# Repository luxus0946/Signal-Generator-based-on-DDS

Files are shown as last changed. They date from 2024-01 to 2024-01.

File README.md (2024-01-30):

# 基于DDS的信号发生器
 ---
### 基本概述

本设计使用STC8H8K64U单片机通过IO端口控制波形发生器AD9833输出波形，经过低通滤波单元接入由MCP41010数字电位器控制的MS8051运放来将产生的信号幅值放大，并且配置了相应的按键输入和液晶屏显示波形的幅值、相位、频率等数据。

### 硬件设计

本设计中基于DDS的多功能信号发生器使用STC8H8K64U实验板通过IO端口控制波形发生器AD9833模块输出波形，经过一个低通滤波单元接入由MCP41010数字电位器控制的MS8051运放进行幅值放大，具体产生的波形、幅值、相位、频率等数据通过液晶屏显示出来，理想测定值通过按键进行人机交互，其中显示单元由12864的液晶模块组成，单片机通过IIC协议控制液晶屏的显示，整个系统通过USB提供电源，外加的接口进行信号的下载和输入。
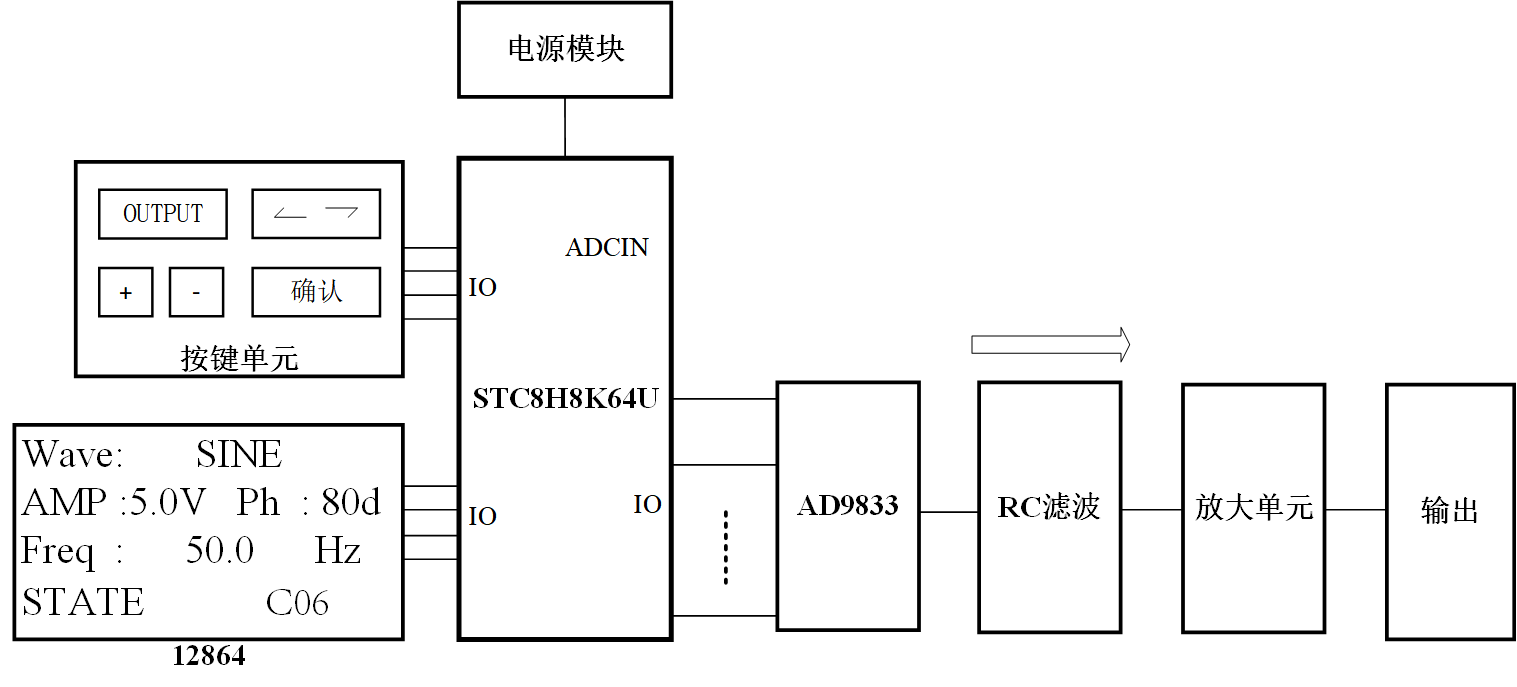
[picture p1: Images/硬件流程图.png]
硬件设计


##### 控制单元
STC8H8K64U具有16个口线，其中P1.4、P1.5、P1.6、P1.7四个口线连接AD9833进行控制主要波形的输出，P1.0、P1.1两个口线连接OLED液晶屏显示波形、幅值、相位、频率等数据信息，P3.4、P3.5、P3.6、P3.7四个口线连接四个按键，进行模式、选择、加和减的控制，P3.3一个口线连接开关进行设置的自锁功能控制，控制单元的电路原理图如下所示。

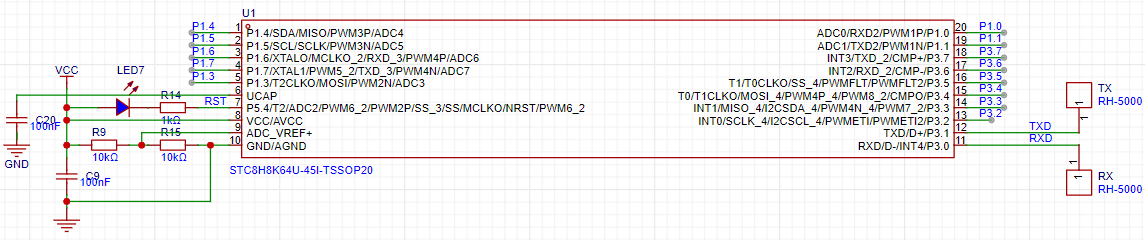
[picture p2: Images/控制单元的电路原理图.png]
控制单元

##### 信号发生模块

DDS的实现方式有两种，即通过程序实现和通过DDS芯片实现，通过程序实现需要DAC模块，通过DDS芯片实现需要AD9833模块，本组课程设计采用通过DDS芯片实现的方式。
在与STC8H8K64U实验板的连接传输过程中，SDATA引脚进行串行数据的输入，SCLK引脚进行串行时钟的输入，FSYNC引脚进行低有效控制的输入，最后通过VOUT引脚输出方波、正弦波、三角波等信号，AD9833信号发生模块的电路原理图如下所示。

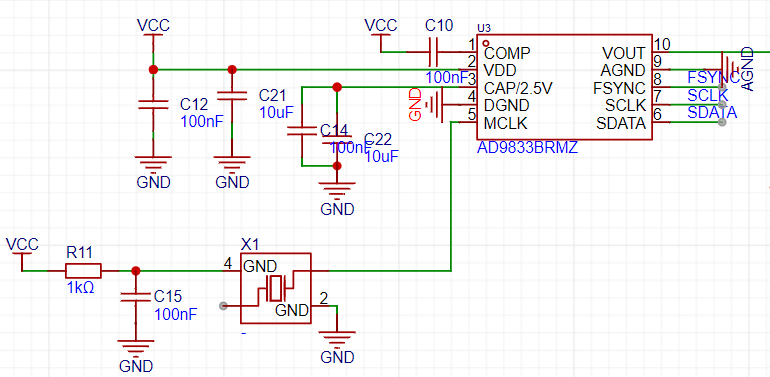
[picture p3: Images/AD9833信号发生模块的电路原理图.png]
信号发生模块


##### 滤波放大模块

考虑到输出的波形可能不是理想的，所以对于AD9833输出的信号采用低通滤波单元进行滤波处理，降低高频噪声对整个系统电路的影响。

由于选用的信号发生器其中自带数字电位器进行阻值调节，所以初步方案的放大单元由MCP41010数字电位器和AD8051运算放大器构成，但在实际测试过程中，AD8051运放的增益带宽积过小，经查阅资料后把AD8051运放改成增益带宽积较大的MS8051运算放大器。

MCP41010数字电位器的CS引脚为数字电位器的片选端，只有为低电平时，命令字和数据字才能进入16位移位寄存器，滤波放大模块的电路原理图如图所示。

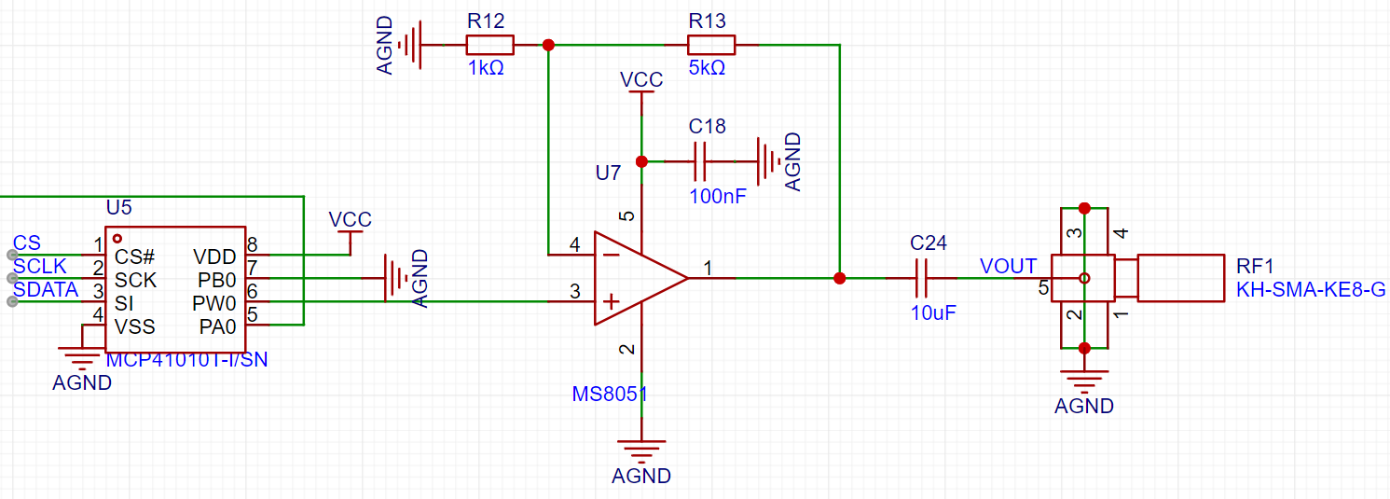
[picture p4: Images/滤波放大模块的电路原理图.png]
滤波放大模块


### 软件设计
本设计中使用Keil5编写C语言程序控制STC8H8K64U通过SPI协议与AD9833芯片进行通信输出波形，复用AD9833占用的SPI口线对MCP41010数字电位器进行控制来调整幅值。具体产生的波形、幅值、相位、频率等数据通过液晶屏显示出来，理想测定值通过按键进行人机交互，其中显示单元由12864的液晶模块组成，单片机通过IIC协议控制液晶屏的显示。程序流程图如下

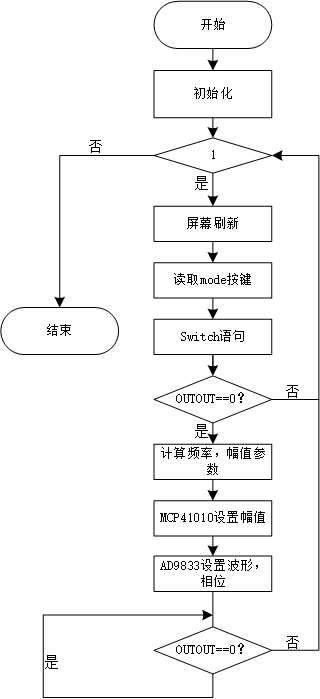
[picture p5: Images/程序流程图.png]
软件设计


#### 相关硬件驱动

##### OLED驱动

我们先对每一个部分进行代码实现，然后调用所实现的函数进行组合发送一个字节的数据。然后根据汉昇的数据手册分别发送命令（command）与数据（data）。我们可以通过发送命令对屏幕进行设置模式，清屏等操作。根据上述流程我们实现我们所需要使用的驱动函数，详细代码细节可见附录，IIC协议的控制流程图如图所示。

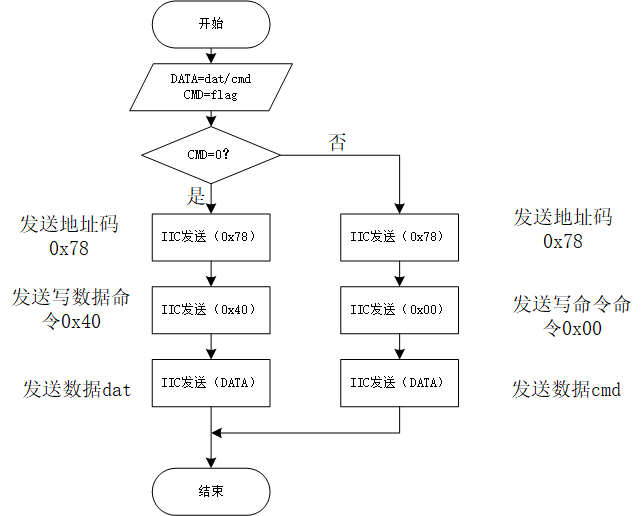
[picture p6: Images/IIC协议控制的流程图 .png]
OLED驱动


##### AD9833驱动 

AD9833是可编程波形发生器,能够产生正弦波、三角波、方波输出。通过软件编程进行控制相位和频率，频率寄存器是28位的。

AD9833有3根串行接口线FSYNC、SCLK、SDATA，在串口时钟SCLK的作用下，数据是以16位的方式加载到设备上，FSYNC引脚是使能引脚，低电平有效。进行串行数据传输时，FSYNC引脚必须置低,要注意FSYNC有效到SCLK下降沿的建立时间t7的最小值。FSYNC置低后，在16个SCLK的下降沿数据被送到AD9833的输入移位寄存器，在第16个SCLK的下降沿FSYNC可以被置高。

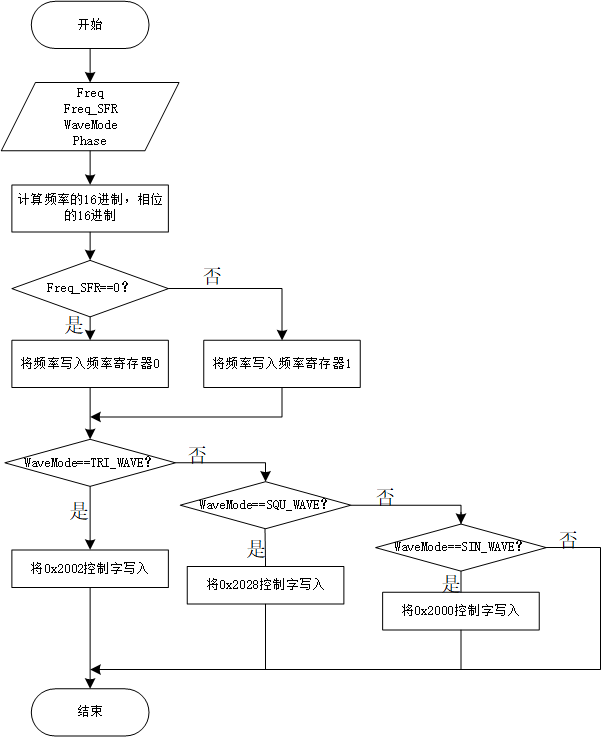
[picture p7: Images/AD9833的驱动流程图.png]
AD9833驱动


##### MCP41010驱动
本方案使用MCP41010数字电位器与MS8051运算放大器组成信号放大单元。MCP41010使用电位器工作模式，MS8051与电阻搭建11倍固定增益放大电路。MCP41010有256个抽头，可以对电压有较为精细的控制。由于我们选用的为MCP41010只有#CS，SCK，SI三条信号线，在写入控制字时需要将CS拉低由于MCP41010的SCK和SI与AD9833的SCLK、SDATA是复用的，所以在写入AD9833控制字时需要吧CS拉高，对MCP41010操作时把CS拉低。否则回发生冲突，无法实现复用，MCP41010控制时序图如图4.7所示，MCP41010的驱动流程图如图所示。

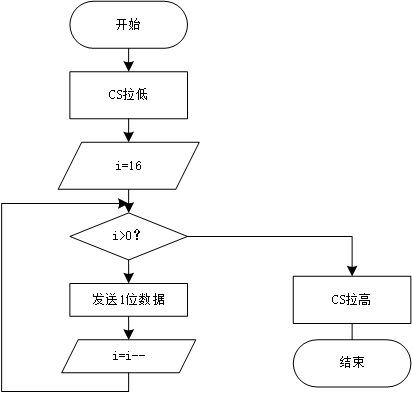
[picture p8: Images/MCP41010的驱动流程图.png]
MCP41010驱动


##### EEPROM驱动
为了更好的用户体验，我们设计了掉电保存上一次输出的参数的功能。我们使用STC8H单片机内部的EEPROM来实现这个功能。STC8H 系列单片机内部集成了大容量的 EEPROM。利用ISP/IAP技术可将内部Data Flash当EEPROM，擦写次数在10万次以上。EEPROM 可分为若干个扇区，每个扇区包含512字节。

本课设采用IAP的方式对EEPROM进行读取执行读、写、擦除操作。在使用过程中我们需要注意IAP只能对擦除后的EEPROM进行写入操作。且其中擦除操作是以扇区为单位进行操作即一次擦除512字节。EEPROM的驱动流程图如图所示。
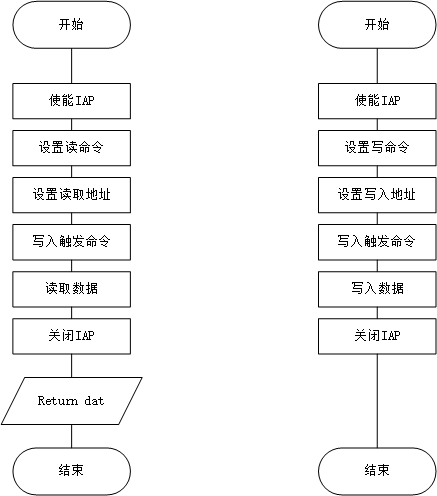
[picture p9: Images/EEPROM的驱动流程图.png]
EEPROM驱动


#### 软件主要分支设计

##### Switch语句设计

本次课设我们需要4个分支分别是波形设置、幅值设置、相位设置、频率设置。我们考虑多种分支结构，最终选用Switch语句。Switch语句设计图如图所示。
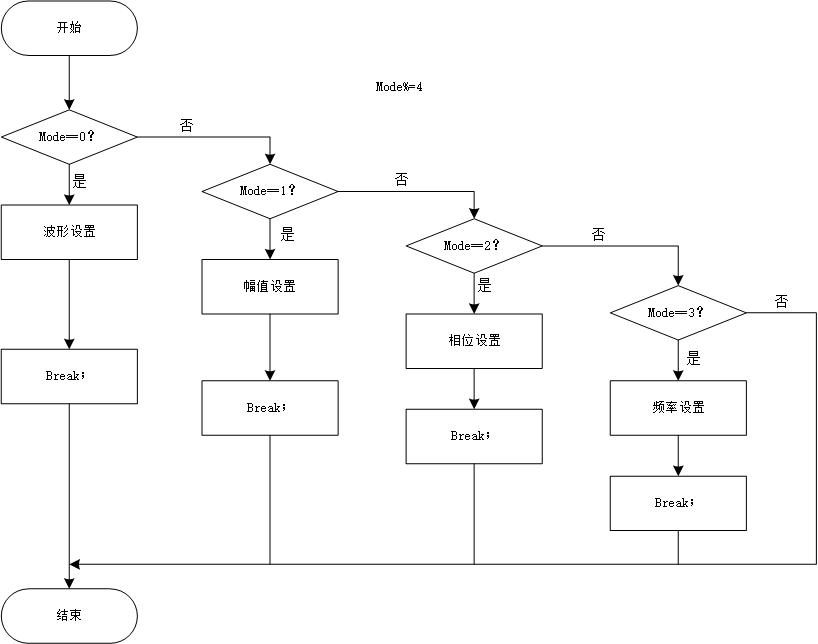
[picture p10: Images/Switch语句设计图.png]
Switch语句设计


##### UI设计
为了更好的用户体验我们设计了开机页面，参数设置页面与输出页面，我们根据OLED屏幕的显示特性，我们只将不同页面中不相同的区域进行更换，提高程序运行的效率。

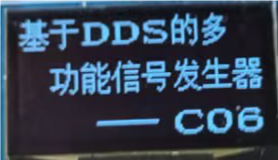
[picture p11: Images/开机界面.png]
开机画面


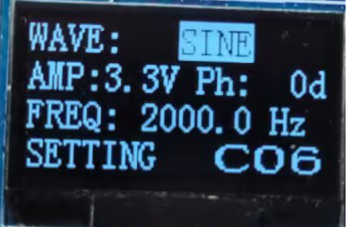
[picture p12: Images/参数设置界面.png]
参数设置


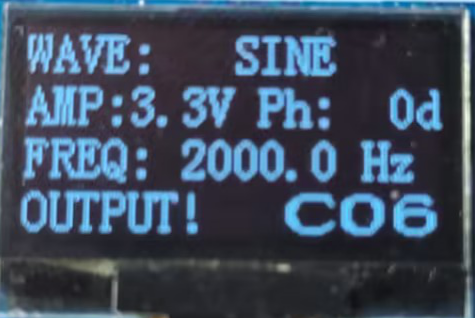
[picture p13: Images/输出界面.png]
输出画面


#### 相关协议

1. IIC协议

输入图片说明

2. AD9833 

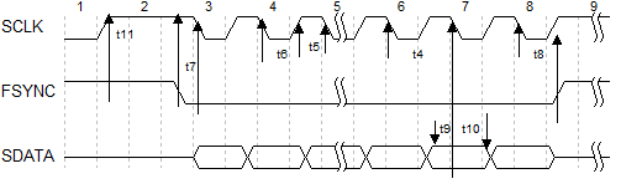
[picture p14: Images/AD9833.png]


3. MCP41010

输入图片说明

#### 相关链接

1.  硬件开源：  https://oshwhub.com/signal-generator-based-on-dds/based-on-dds
### 后记

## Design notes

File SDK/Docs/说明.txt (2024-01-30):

引脚定义
OLED
SDA     P1.0
SCL     P1.1

AD9833
FSYNC   P1.4
SCLK    P1.5
SDATA   P1.6
CS      P1.7

KEY
SELECT  P3.4
MODE    P3.5
SUB     P3.6
ADD     P3.7
OUTPUT  P3.3

STC8H
RXD     P3.0
TXD     P3.1
RST     P5.4

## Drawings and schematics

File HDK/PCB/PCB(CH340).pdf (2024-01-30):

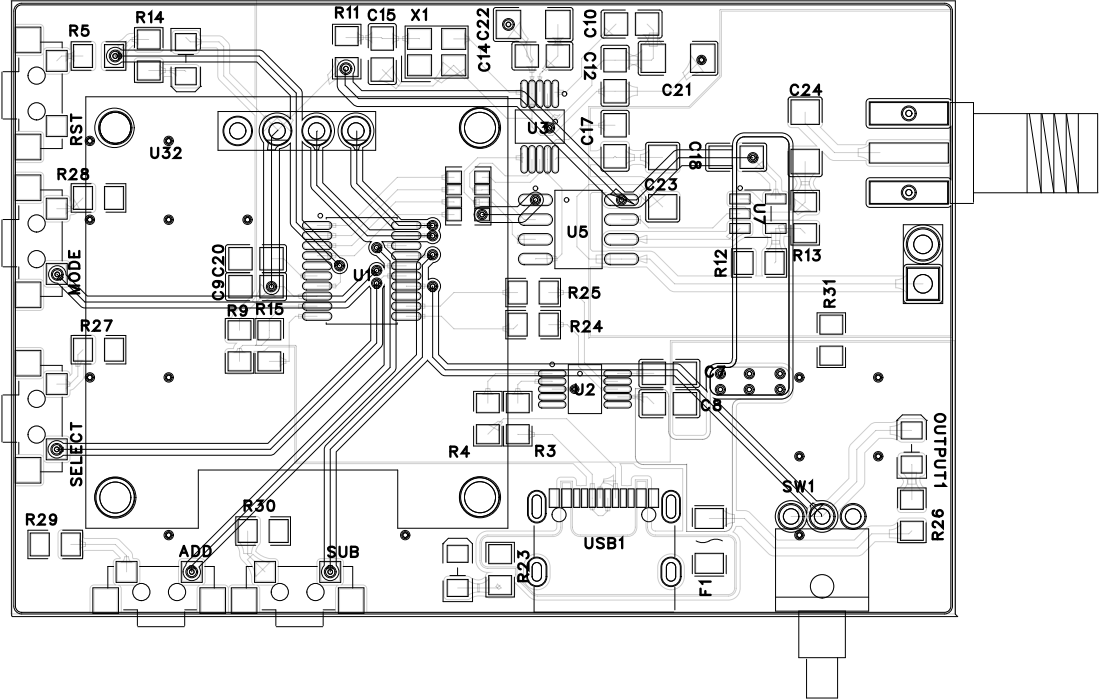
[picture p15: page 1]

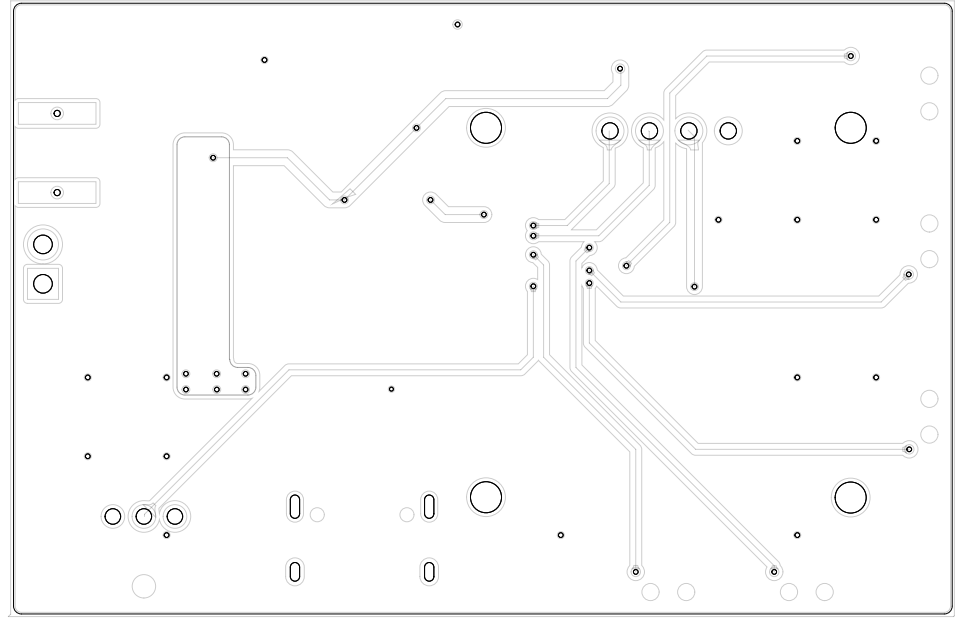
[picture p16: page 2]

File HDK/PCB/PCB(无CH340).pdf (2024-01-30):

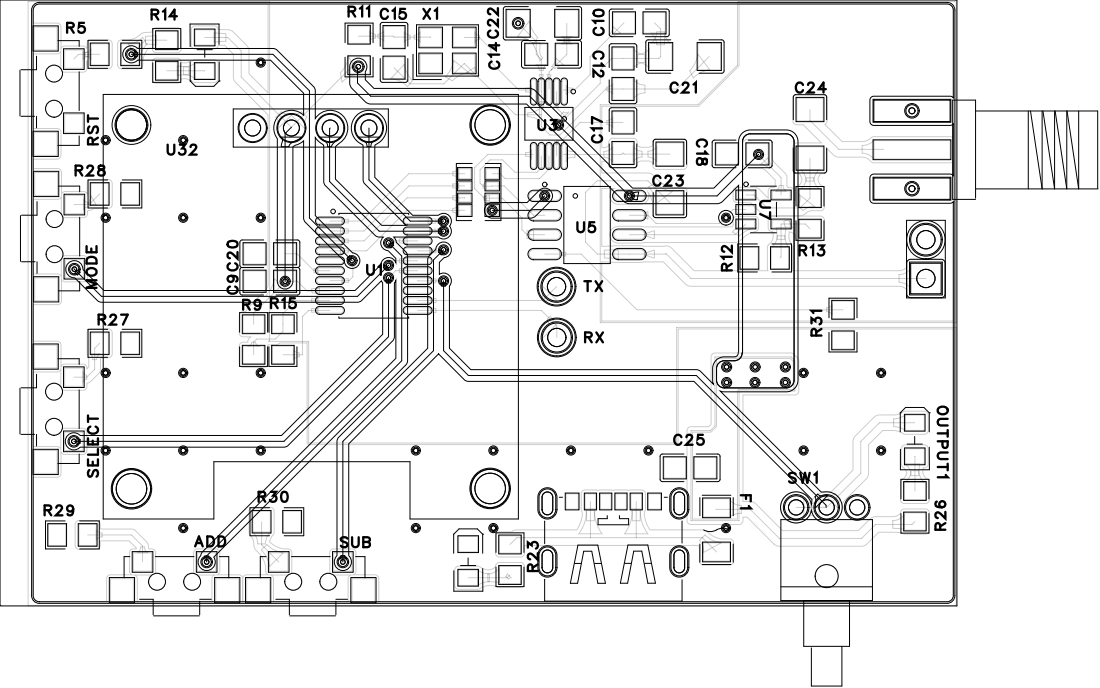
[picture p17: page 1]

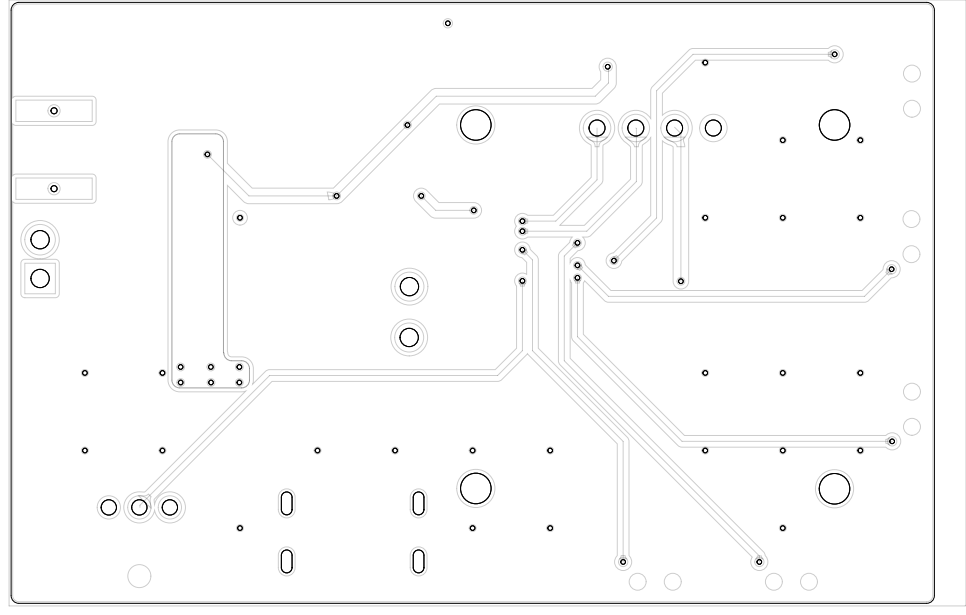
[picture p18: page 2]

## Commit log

2024-01-30 删除文件 README.en.md
2024-01-30 删除文件 Imagesall.png
2024-01-30 删除文件 Images程序流程图.png
2024-01-30 删除文件 Images图片1.png
2024-01-30 删除文件 Images图片2.png
2024-01-30 删除文件 Images图片3.png
2024-01-30 重命名 Images/图片1.png 为 Images/IIC.png
2024-01-30 重命名 Images/图片3.png 为 Images/MCP41010.png
2024-01-30 重命名 Images/图片2.png 为 Images/AD9833.png
2024-01-30 重命名 Images/all.png 为 Images/程序流程图.png
2024-01-30 重命名 Images/流程图3.png 为 Images/硬件流程图.png
2024-01-30 新建 PCB
2024-01-30 删除文件 HDK/PCB/.keep
2024-01-30 新建 3D仿真图
2024-01-30 新建 SDK
2024-01-30 新建 原理图
2024-01-30 新建 based-on-dds(含有CH340)
2024-01-30 新建 based-on-dds(无CH340)
2024-01-30 删除文件 HDK/原理图/.keep
2024-01-30 删除文件 HDK/原理图/based-on-dds(无CH340)/.keep
2024-01-30 删除文件 HDK/3D仿真图/.keep
2024-01-30 新建 Docs
2024-01-30 新建 hardware
2024-01-30 重命名 SDK/hardware/.keep 为 SDK/hardware/readme.md
2024-01-30 重命名 SDK/.keep 为 SDK/readme.md
2024-01-30 重命名 SDK/Docs/.keep 为 SDK/Docs/readme.md
